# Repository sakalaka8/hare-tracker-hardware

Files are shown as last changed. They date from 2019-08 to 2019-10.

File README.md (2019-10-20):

# Hare tracker hardware

Device is LoRa tracker which incudes MCU, GPS and a few sensors for enviromental monitoring.

Main components:
- Top:
    - Murata ABZ (MCU + LoRa)
    - Bosch BME280 (Microclimate sensor)
    - AMS TSL2591 (Light sensor)
    - Power supply components:
        - STM USBLC6 (ESD protection)
        - Texas Instruments TPS62740DSSR (Buck converter)

- Bottom:
    - Ublox MAX M8Q0 (GPS)
    - ST LIS2DH12 (Accelerometer)
    - Power supply components:  
        - Microchip MCP73831T (Battery charger)

PCB specifications:
- Device dimensions: 30x30 mm
- Device weight: ~30 g
- PCB thickness: 1.6mm 
- Trace to trace and trace to polygon clearance: 0.152mm (6mil)
- RF line thickness: 1.016mm (40 mil)

Assembled view
 
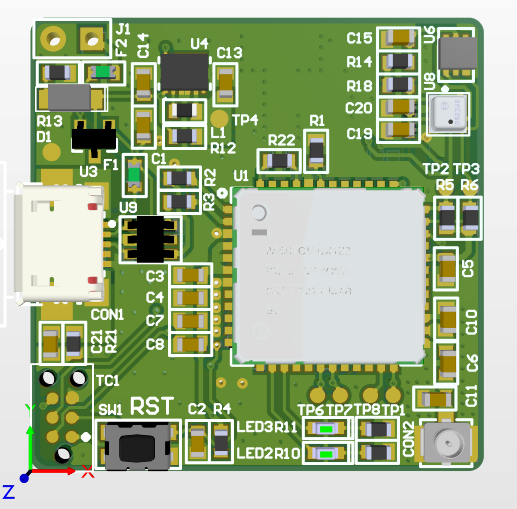
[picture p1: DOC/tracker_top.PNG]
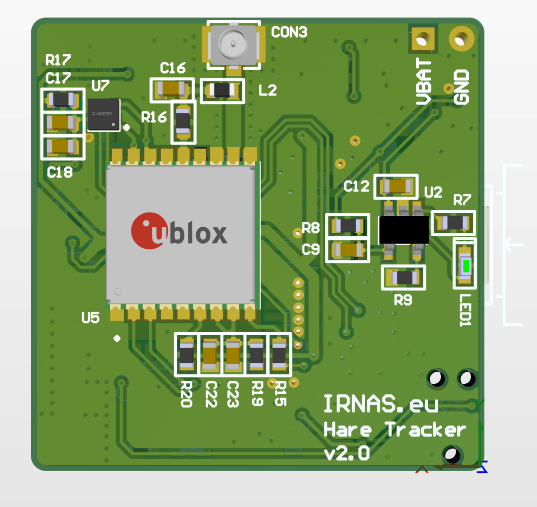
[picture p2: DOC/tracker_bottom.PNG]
						

Main power supply is from lithium-ion battery.

To do:
* For lower power consumption add MOSFET (DMG6602) between MCU pin and GPS power pin.
* Change buck converter for lower power consumption.

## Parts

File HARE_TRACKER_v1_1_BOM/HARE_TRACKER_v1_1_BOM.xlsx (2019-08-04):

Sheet: Part List Report
 | Component list |  |  | <Parameter ProjectTitle not found>
 | Source Data From: | Tracker_v1_1.PrjPCB |  |  | Contact:
 | Project: | Tracker_v1_1.PrjPCB
 | Variant: | None |  |  |  |  |  |  | IRNAS
 | Report Date: | 4. 07. 2019 | 09:55 |  |  |  |  |  | www.irnas.eu
 | Print Date: | 2019-07-04 | 9:55:34
# | Manufacturer Part Number 1 | Manufacturer 1 | Description | Footprint | Designator | Quantity | Supplier 1 | Supplier Part Number 1 | Supplier Order Qty 1 | Supplier Stock 1 | Supplier Unit Price 1 | Supplier Subtotal 1 | Supplier Currency 1
1 |  |  | CAP CER 10UF 10V X5R 0603 | C0603 | C1, C4, C8, C13, C14, C17, C20, C23 | 8 | Farnell | 2820985RL
2 |  |  | CAP CER 0.1UF 25V X7R 0603 | C0603 | C2, C3, C7, C9, C10, C11, C18, C19, C21, C22 | 10 | Farnell | 1650833RL
3 |  |  | Cap Ceramic 1uF 10V X7R 10% SMD 0603 125C T/R | C0603 | C5, C15 | 2 | Farnell | 2522396RL
4 |  |  | Cap Ceramic 100pF 50V C0G 10% SMD 0603 125C Paper T/R | C0603 | C6 | 1 | Farnell | 1823375
5 |  |  | CAP CER 4.7UF 6.3V X5R 0603 | C0603 | C12 | 1 | Farnell | 1310155
6 |  |  | 0603 C 10nF Ceramic Multilayer Capacitor, 25 V, +125degC, C0G Dielectric, +/-5% | C0603 | C16 | 1 | Digi-Key | C0603C103J3GACTU-ND
7 |  |  | AMPHENOL FCI - 10104110-0001LF - MICRO USB, 2.0 TYPE B, RECEPTACLE, SMT | MICRO usb conn | CON1 | 1 | Farnell | 2293753
8 |  |  | RF Connectors / Coaxial Connectors MCX V PCB JACK SMT 1.25MM MNT HGT | Antena connector | CON2, CON3 | 2 | Farnell | 1340200
9 |  |  | DIODE SCHOTTKY 20V 1A SOD123FL | MBR120VLSFT1G | D1 | 1 | Farnell | 2393584
10 |  |  | FUSE BOARD MNT 1.5A 32VAC 65VDC | Fuse | F1, F2 | 2 | Farnell | 1596948RL
11 |  |  |  | HEADER 2X1 | J1 | 1
12 |  |  | FIXED IND 2.2UH 2A 80 MOHM SMD | L0603 | L1 | 1 | Digi-Key | 399-9598-6-ND
13 |  |  | Inductor RF Chip Multi-Layer 27nH 5% 100MHz 12Q-Factor Air 300mA 550mOhm DCR 0603 T/R | L0603 | L2 | 1 | Digi-Key | 490-6579-2-ND
14 |  |  | KINGBRIGHT - KP-1608CGCK - LED, 0603, 50MCD, GREEN | LED_0603 | LED1, LED2, LED3 | 3 | Farnell | 2290328
15 |  |  |  | MH_NC | MH1, MH2, MH3, MH4 | 4
16 |  |  | RES 10K OHM 5% 0.01W 0603 | R0603 | R1, R4 | 2 | Farnell | 2752989RL
17 |  |  | RES SMD 27 OHM 1% 1/10W 0603 | R0603 | R2, R3 | 2 | Farnell | 1151876
18 |  |  | Res Thick Film 0603 4.7K Ohm 5% 1/10W ±200ppm/°C Molded SMD SMD Paper Tape on Plastic Reel | R0603 | R5, R6 | 2 | Farnell | 2371774
19 |  |  | Res Thick Film 0603 510 Ohm 5% 1/10W ±200ppm/°C Molded SMD SMD Paper Tape on Plastic Reel | R0603 | R7, R10, R11 | 3 | Farnell | 2908378
20 |  |  | RES 0 OHM JUMPER 1/10W 0603 | R0603 | R8, R12, R14, R15, R17, R18, R19, R20, R22 | 9 | Digi-Key | RMCF0603ZT0R00-ND
21 |  |  | Res Thick Film 0603 2K Ohm 5% 1/10W ±200ppm/°C Molded SMD SMD Paper Tape on Plastic Reel | R0603 | R9 | 1 | Farnell | 2787805RL
22 |  |  | TE CONNECTIVITY CPF-A-0603B100KE1 SMD Chip Resistor, Thin Film, 100 kohm, 50 V, 0603 [1608 Metric], 62.5 mW, 0.1%, CPF-A Series | R0603 | R13, R21 | 2 | Farnell | 2483881RL
23 |  |  | RES SMD 10 OHM 1% 1/10W 0603 | R0603 | R16 | 1 | Digi-Key | 541-10.0HTR-ND
24 |  |  | SWITCH TACTILE SPST-NO 0.05A 32V | Button | SW1 | 1 | Farnell | 1437635RL
25 |  |  |  | TC2030 | TC1 | 1
26 |  |  | TEST POINT ROUND SMD | TEST POINT 1X1mm | TP1, TP2, TP3, TP4, TP5, TP6, TP7, TP8 | 8
27 |  |  | MURATA - CMWX1ZZABZ-091 - RF MODULE, 860-930MHZ, 4.8KBPS, 18.5DBM | Murata ABZ | U1 | 1 | Farnell | 2802546
28 |  |  | MICROCHIP - MCP73831T-2ACI/OT - LI-ION/LI-POLY CHARGE CONTROLLER | MCP73831T-2ACI/OT | U2 | 1 | Farnell | 1332158
29 |  |  | MOSFET P-CH 20V 4A SOT-23 | DMG3415U-7 | U3 | 1 | Farnell | 1843688RL
30 |  |  | Switching Voltage Regulators 360-nA Iq SD Cnvtr w/ Intg Load Switch | TPS62740DSSR | U4 | 1 | Farnell | 2542791
31 |  |  | Rf Rcvr Gnss/gps 1.575GHZ 18LCC | Ublox MAX M8 | U5 | 1 | Digi-Key | 672-1003-6-ND
32 |  |  | IC LIGHT TO DGTL CONV 6-DFN | TSL2591 | U6 | 1 | Digi-Key | TSL25911FNTR-ND
33 |  |  | STMICROELECTRONICS - LIS2DH12TR - 3-AXIS ACCELEROMETER, DIGITAL, LGA-12 | LIS2DH12 | U7 | 1 | Farnell | 2433081RL
34 |  |  | Pressure, Temperature and Humidity Sensor Digital Output 1.8V 8-Pin LGA T/R | BME280 | U8 | 1 | Digi-Key | 828-1063-2-ND
35 |  |  | TVS DIODE 5.25V 17V SOT23-6 | USBLC6-2SC6 | U9 | 1 | Farnell
 |  |  |  |  |  | 80 |  |  | 0 |  |  | 0
Approved |  |  |  | Notes
 |  |  |  | pcs: |  | 1 |  | Total |  | 0 |  | USD
 |  |  |  |  |  |  |  | Price for 1pcs |  | 0.00 |  | USD

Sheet: Project Information
Project Full Path | C:\Users\Tadej\Documents\Diplomska_naloga\Tracker_v1_1\Tracker_v1_1.PrjPCB
Project Filename | Tracker_v1_1.PrjPCB
Variant Name | None
Data-Source Filename | Tracker_v1_1.PrjPCB
Data-Source Full Path | C:\Users\Tadej\Documents\Diplomska_naloga\Tracker_v1_1\Tracker_v1_1.PrjPCB
Title | BOM for Project [Tracker_v1_1.PrjPCB] (No PCB Document Selected)
Total Quantity | 80
Report Time | 09:55
Report Date | 4. 07. 2019
Report Date & Tine | 4. 07. 2019 09:55
Output Name | BOM
Output Type | BOM_PartType
Output Generator Name | BOM
Output Generator Description | Bill of Materials

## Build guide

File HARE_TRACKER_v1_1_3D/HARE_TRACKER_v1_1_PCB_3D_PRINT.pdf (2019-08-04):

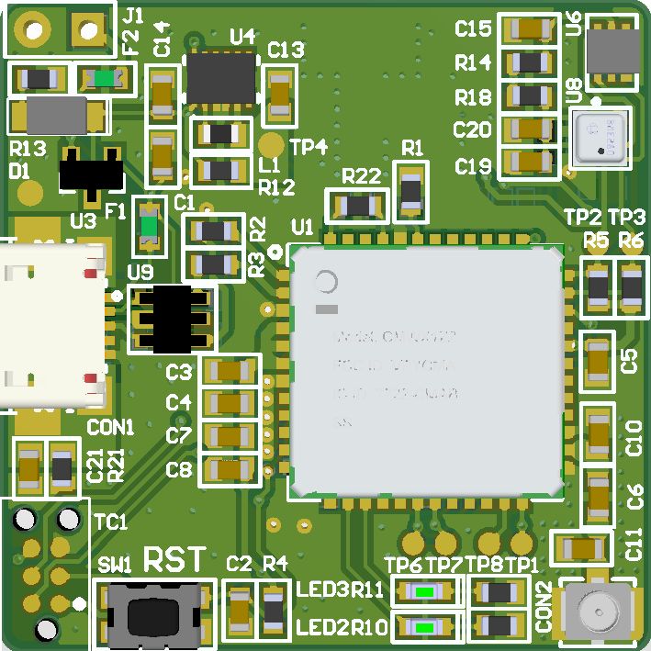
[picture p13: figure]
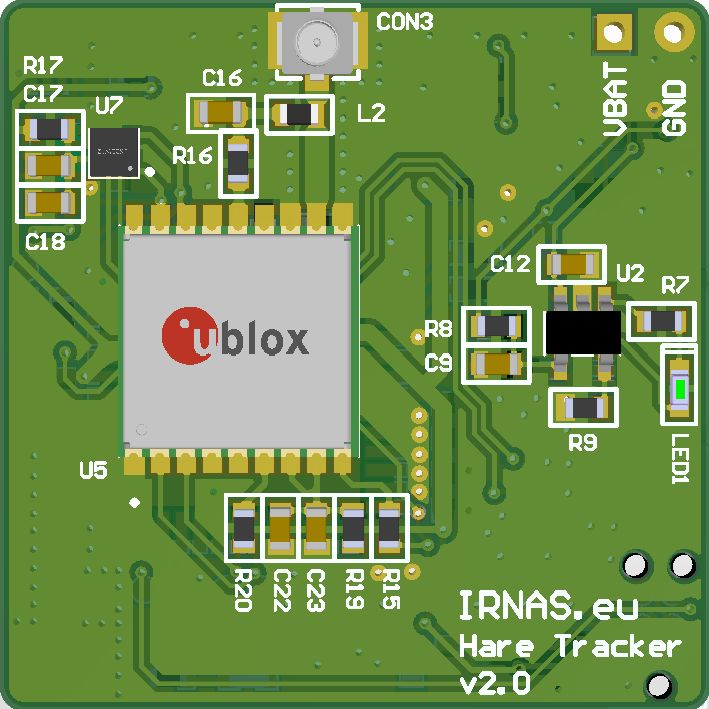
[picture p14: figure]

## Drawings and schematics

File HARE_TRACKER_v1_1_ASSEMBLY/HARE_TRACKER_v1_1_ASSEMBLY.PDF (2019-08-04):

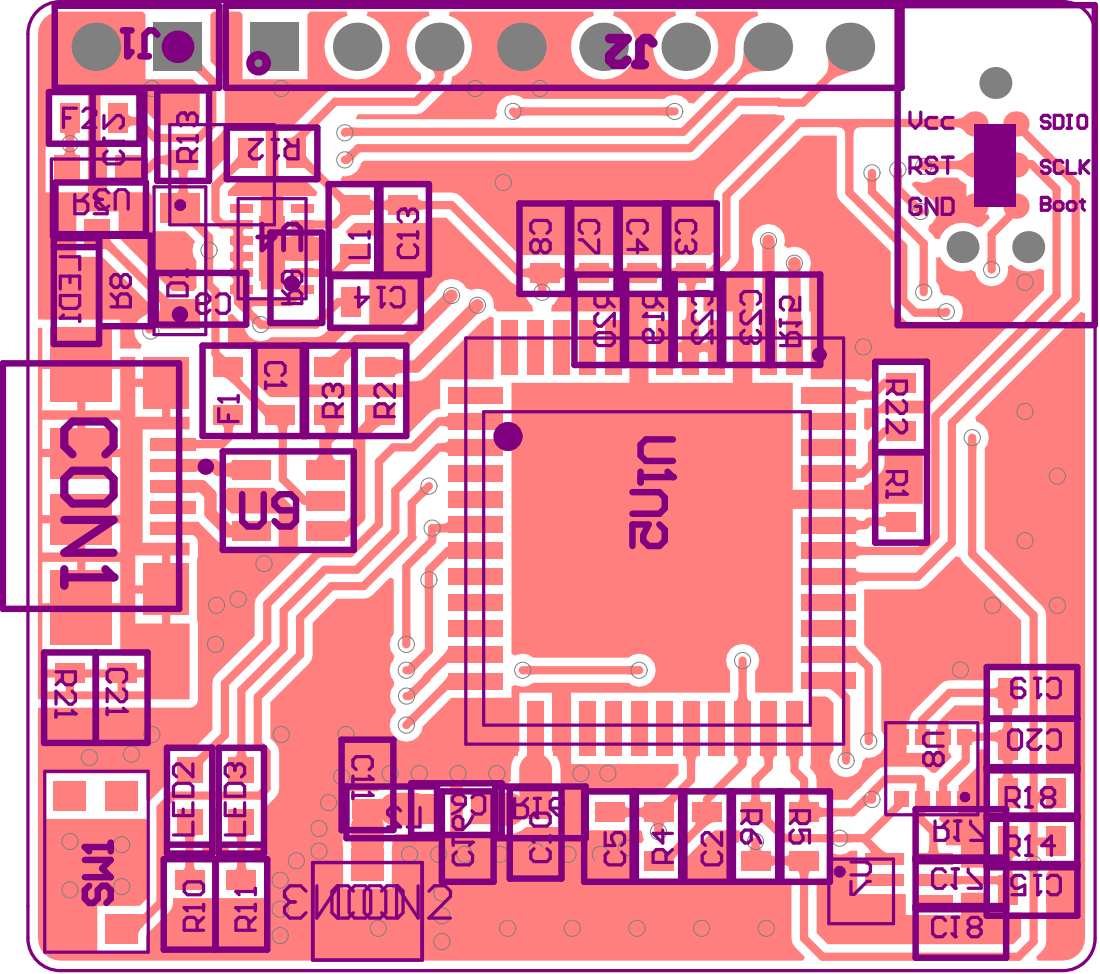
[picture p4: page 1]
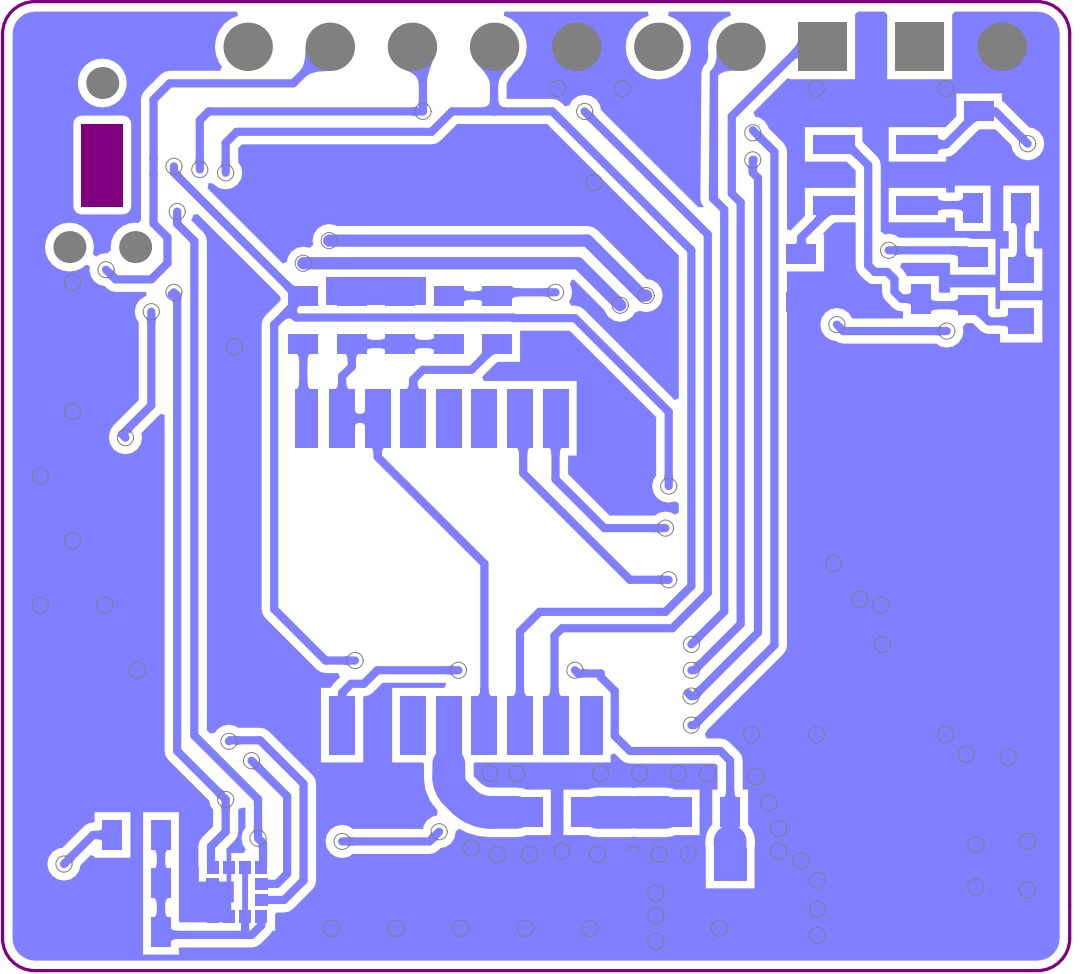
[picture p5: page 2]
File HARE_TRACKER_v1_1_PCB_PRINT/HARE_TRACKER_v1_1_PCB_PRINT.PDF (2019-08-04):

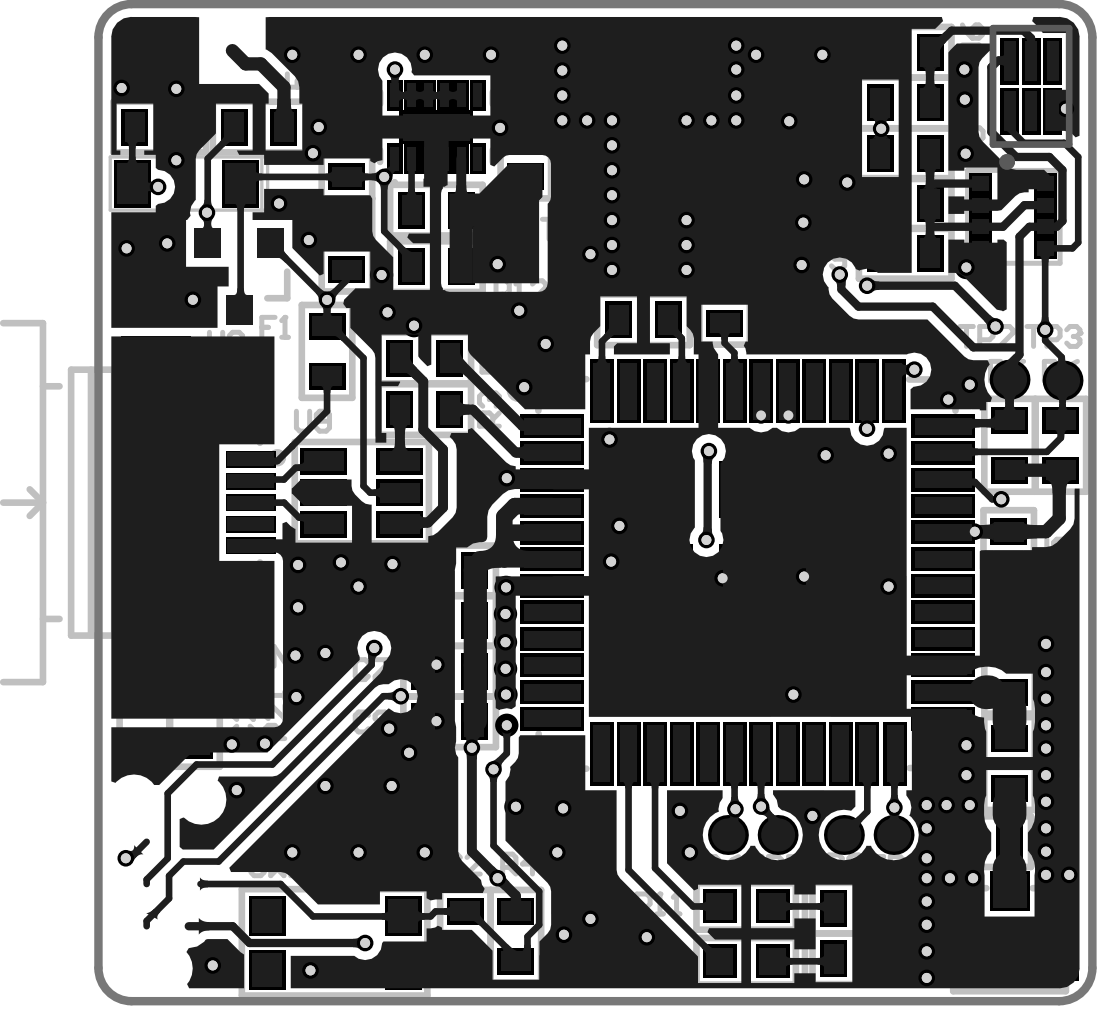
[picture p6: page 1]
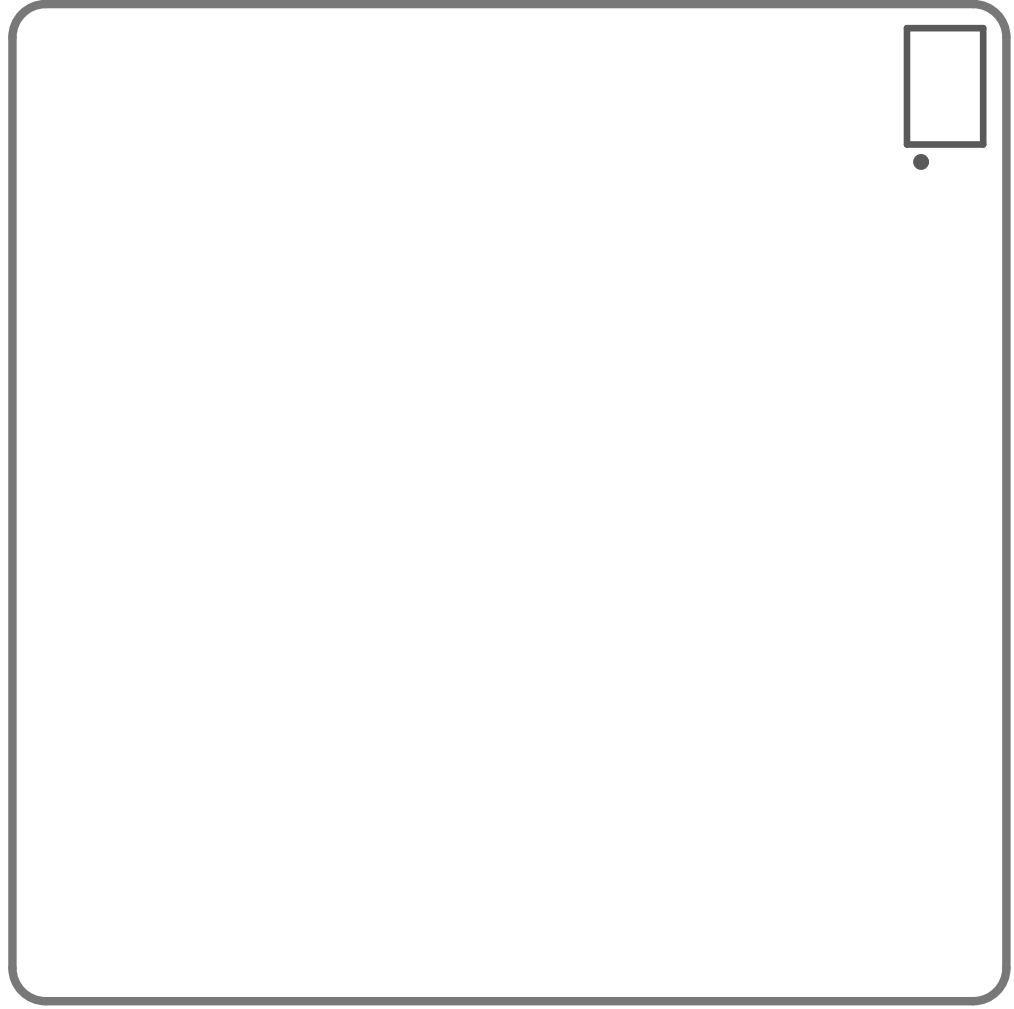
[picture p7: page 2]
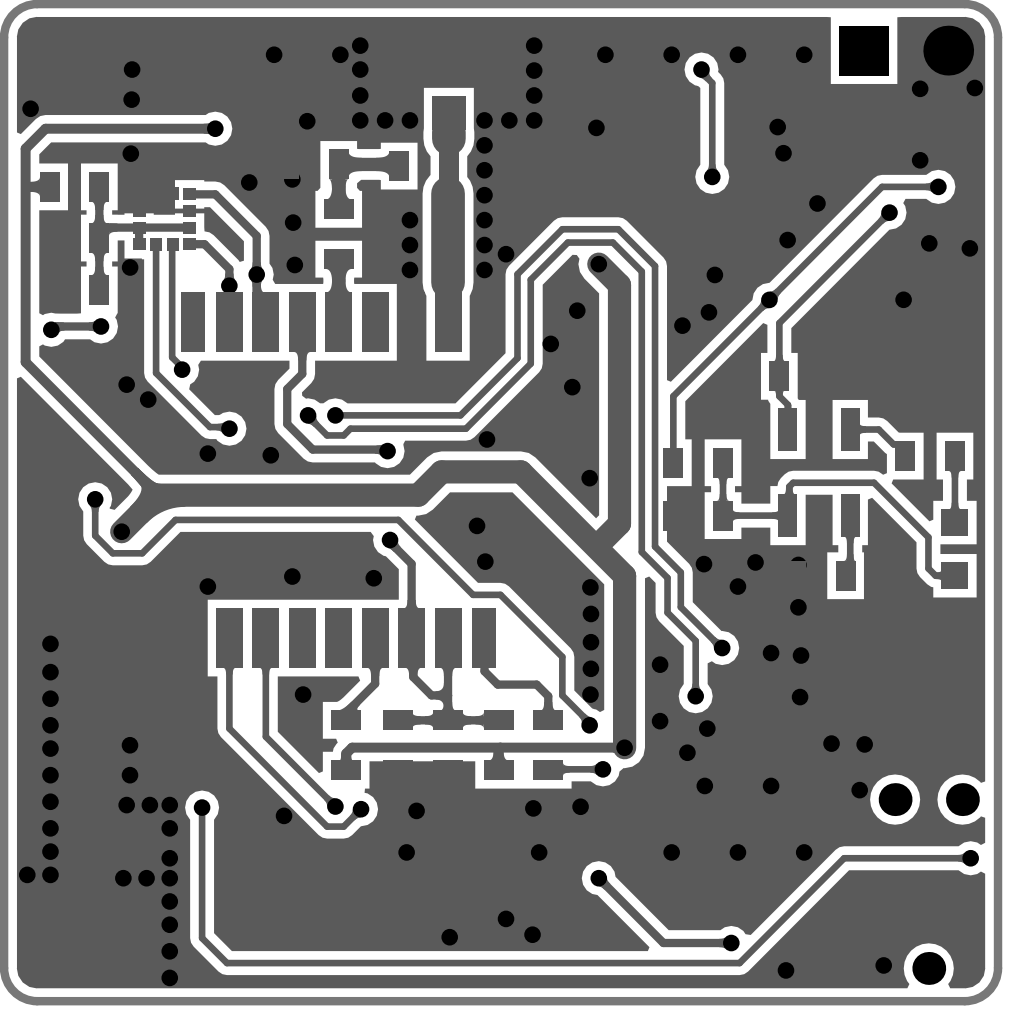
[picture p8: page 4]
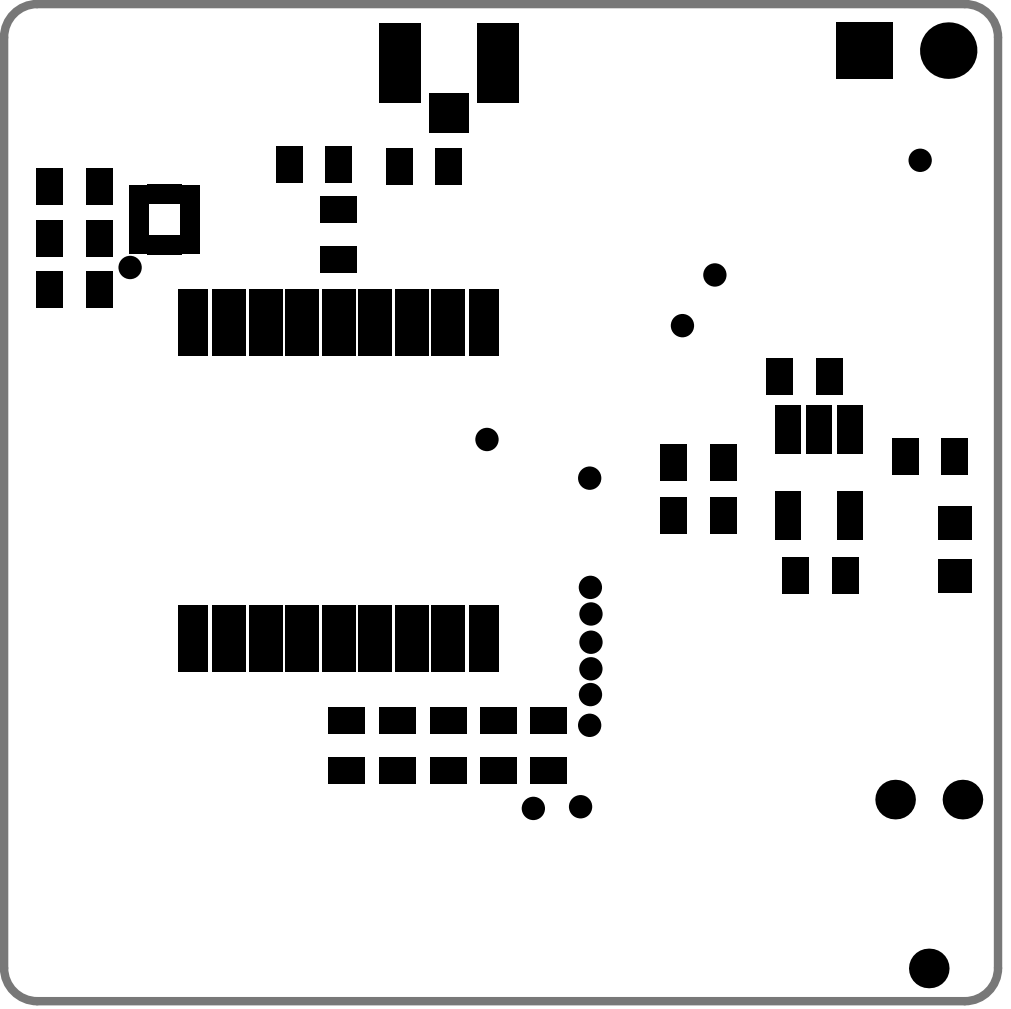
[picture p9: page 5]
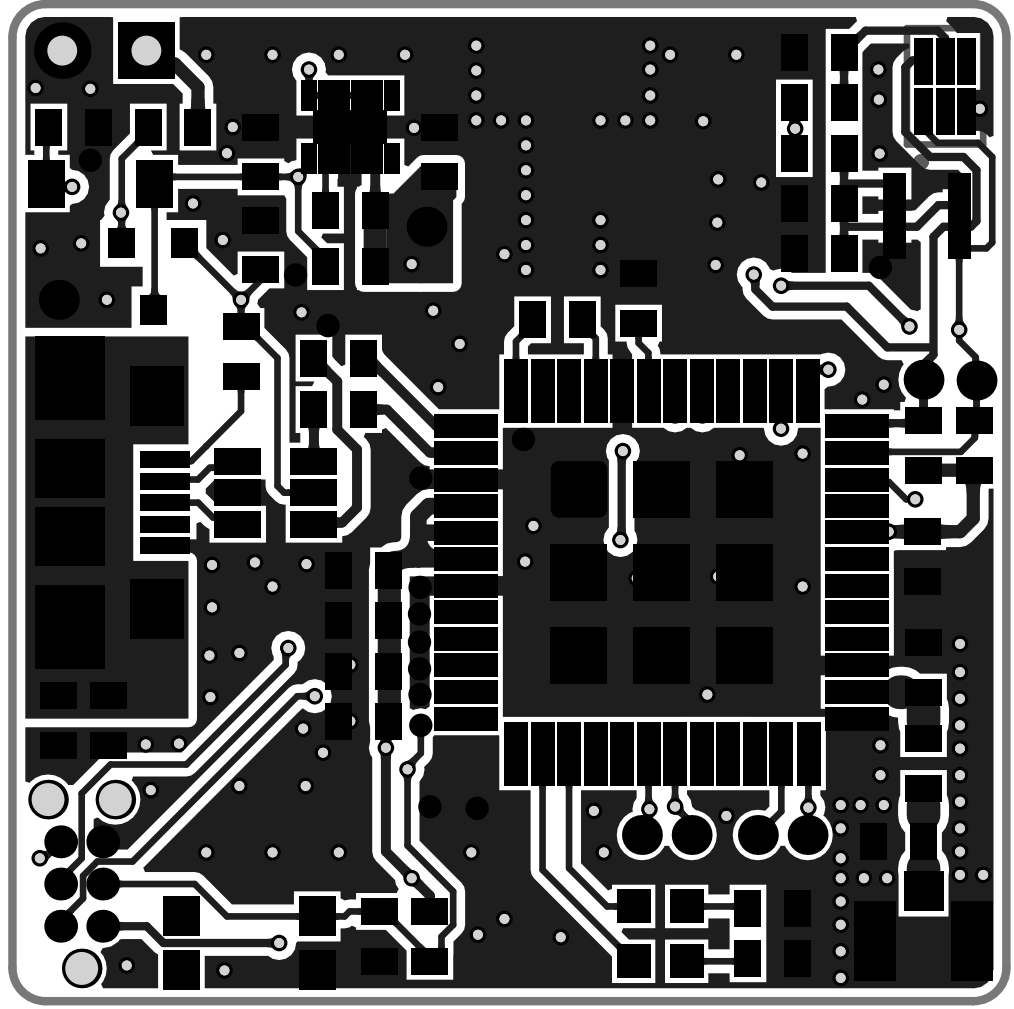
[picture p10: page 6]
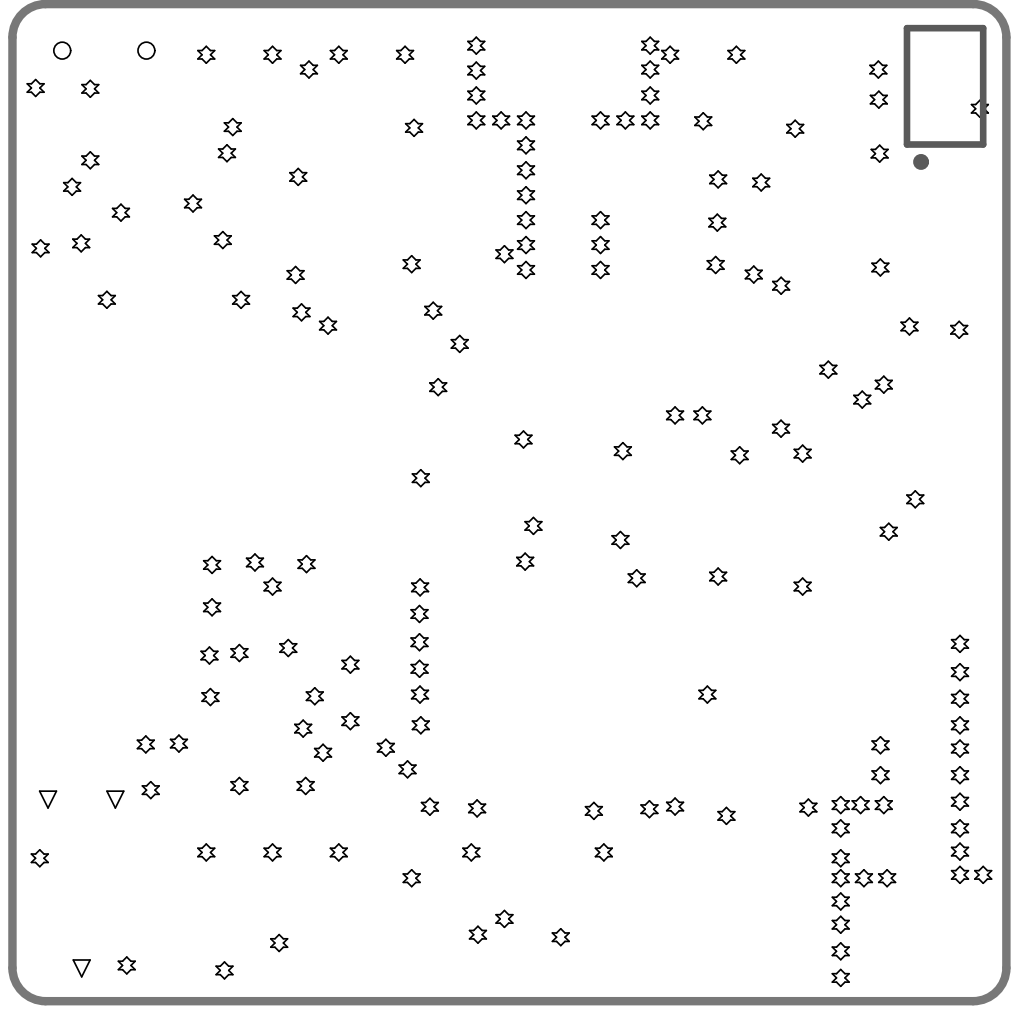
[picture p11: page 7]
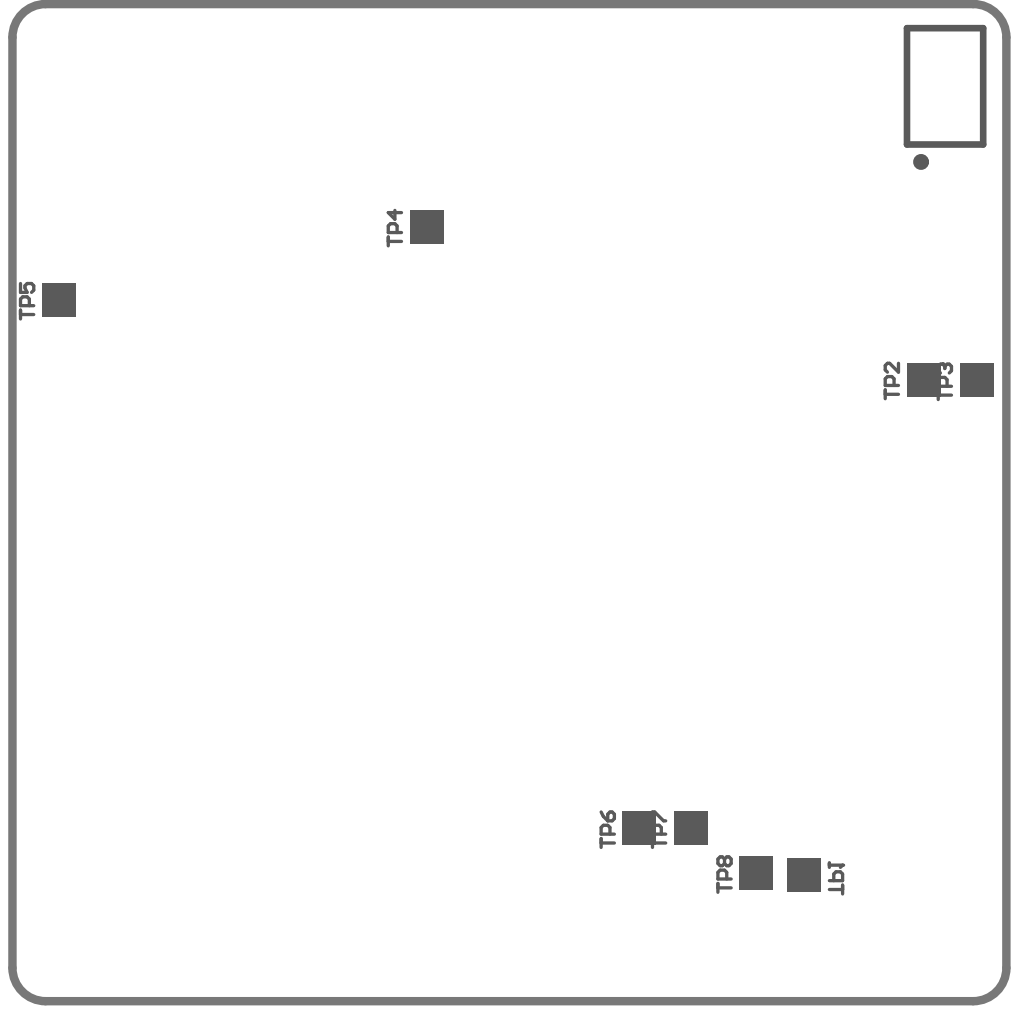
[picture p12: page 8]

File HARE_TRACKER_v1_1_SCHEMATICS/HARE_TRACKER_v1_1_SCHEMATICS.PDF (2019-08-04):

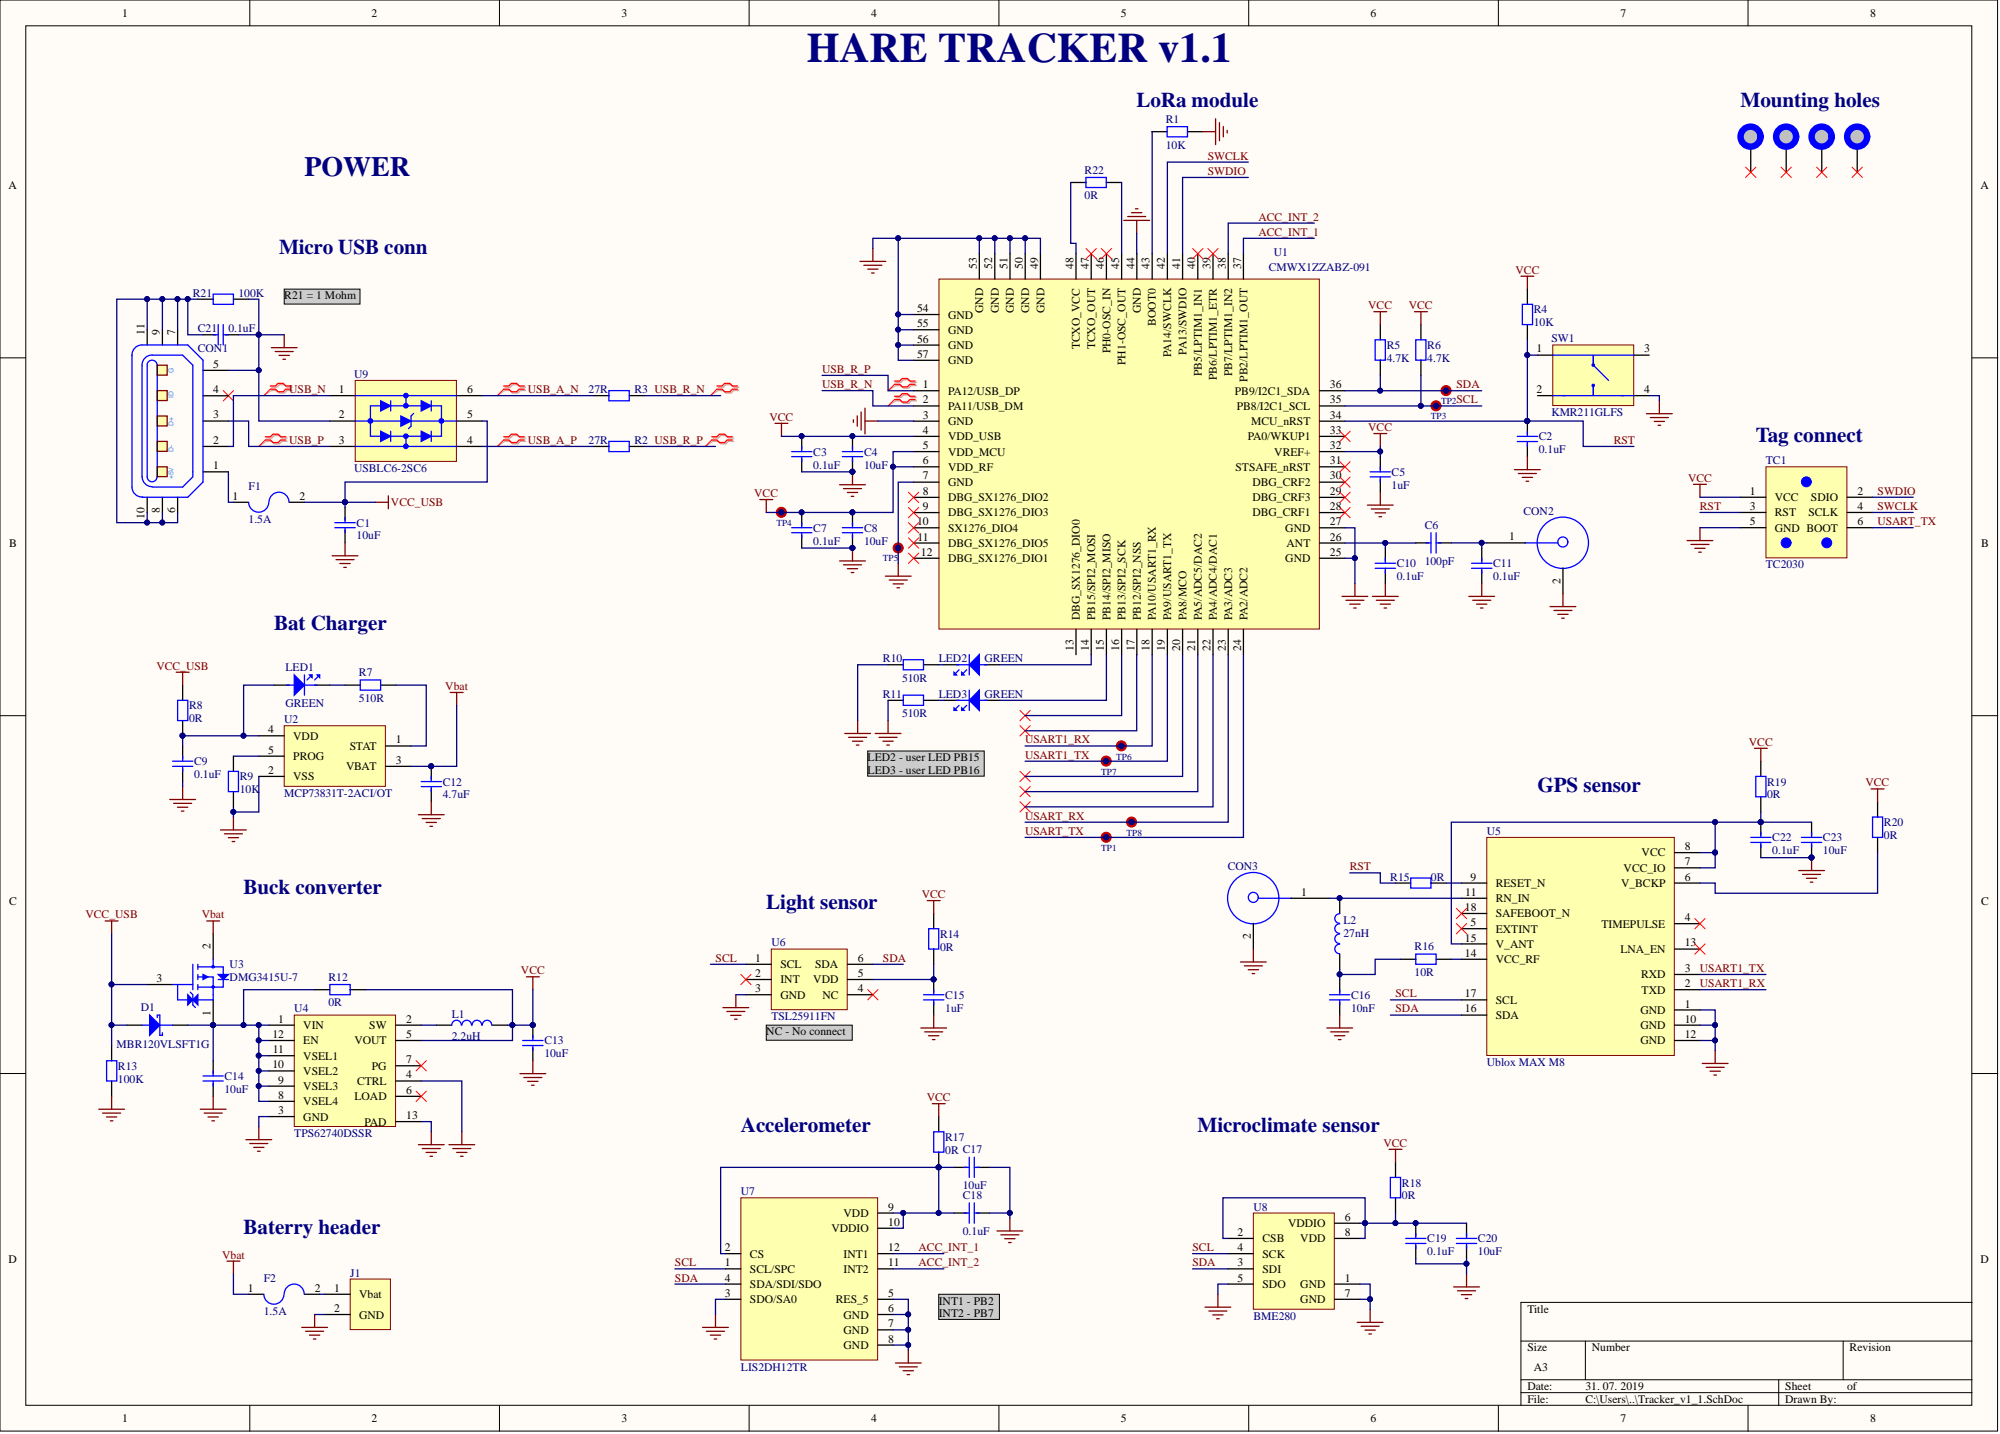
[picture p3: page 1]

GND 50 GND 51 GND 52 GND 53

4 | USB_N

PA11/USB_DM 2 | | SCL TP2
GND 3 | | TP3
